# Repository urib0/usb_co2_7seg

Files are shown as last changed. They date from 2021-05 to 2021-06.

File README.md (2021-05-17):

# usb_co2_7seg

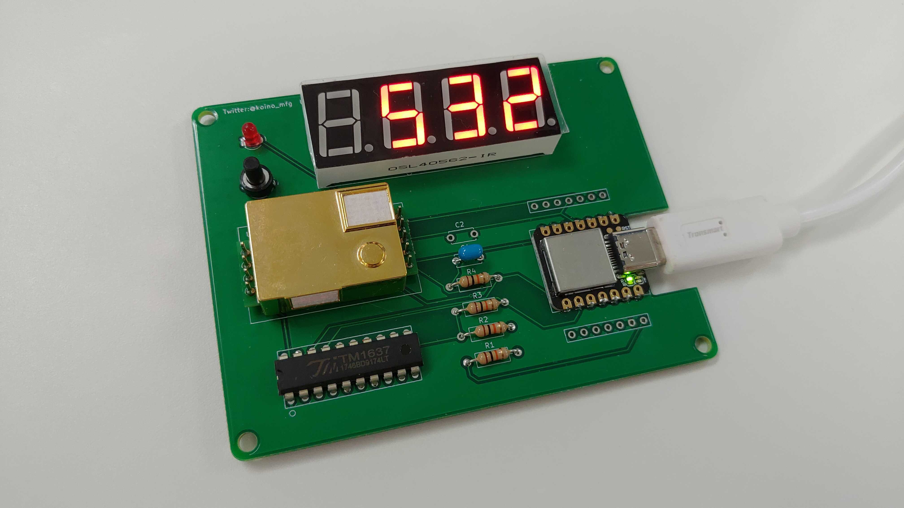
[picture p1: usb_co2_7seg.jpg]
usb_co2_7seg


Mac, Linux マシンに USB で接続できて追加ドライバ不要で値を読める CO2 と 7 セグ表示器

## 使い方(macOS)

まず、USB 機器をすべてコンピュータから取り外す。

次に、usb_co2_7seg を USB ポートに接続する。

次に、コンピュータに接続されているシリアルポートの一覧を表示する。

```
$ ls -1 /dev/cu.*
/dev/cu.Bluetooth-Incoming-Port
/dev/cu.iMiminashi5s-WirelessiAP
/dev/cu.usbmodem14101
```

上記の例の場合、`cu.usbmodem14101` というデバイスファイルが usb_co2_7seg を示す。

次に、`stty`コマンドを実行してシリアルポートの設定を行う。

```sh
stty -f /dev/cu.usbmodem14101 raw 9600
```

最後に、`cat`コマンドでデバイスファイルを読み込むと CO2 の値(ppm)が表示される。

```
$ cat /dev/cu.usbmodem14101
co2=399;status=0
co2=399;status=0
co2=399;status=0
co2=399;status=0
co2=399;status=0
co2=399;status=0
```

## 使い方(Linux)

まず、USB 機器をすべてコンピュータから取り外す。

次に、usb_co2_7seg を USB ポートに接続する。

次に、コンピュータに接続されているシリアルポートの一覧を表示する。

```
$ ls -1 /dev/tty*
/dev/tty
.
. (中略)
.
/dev/ttyACM0
/dev/ttyAMA0
/dev/ttyprintk
/dev/ttyUSB0
```

上記の例の場合、`/dev/ttyACM0` というデバイスファイルが usb_co2_7seg を示す。

次に、`stty`コマンドを実行してシリアルポートの設定を行う。

```sh
stty -F /dev/ttyACM0 raw 9600
```

最後に、`cat`コマンドでデバイスファイルを読み込むと CO2 の値(ppm)が表示される。

```
$ cat /dev/ttyACM0
co2=399;status=0
co2=399;status=0
co2=399;status=0
co2=399;status=0
co2=399;status=0
```

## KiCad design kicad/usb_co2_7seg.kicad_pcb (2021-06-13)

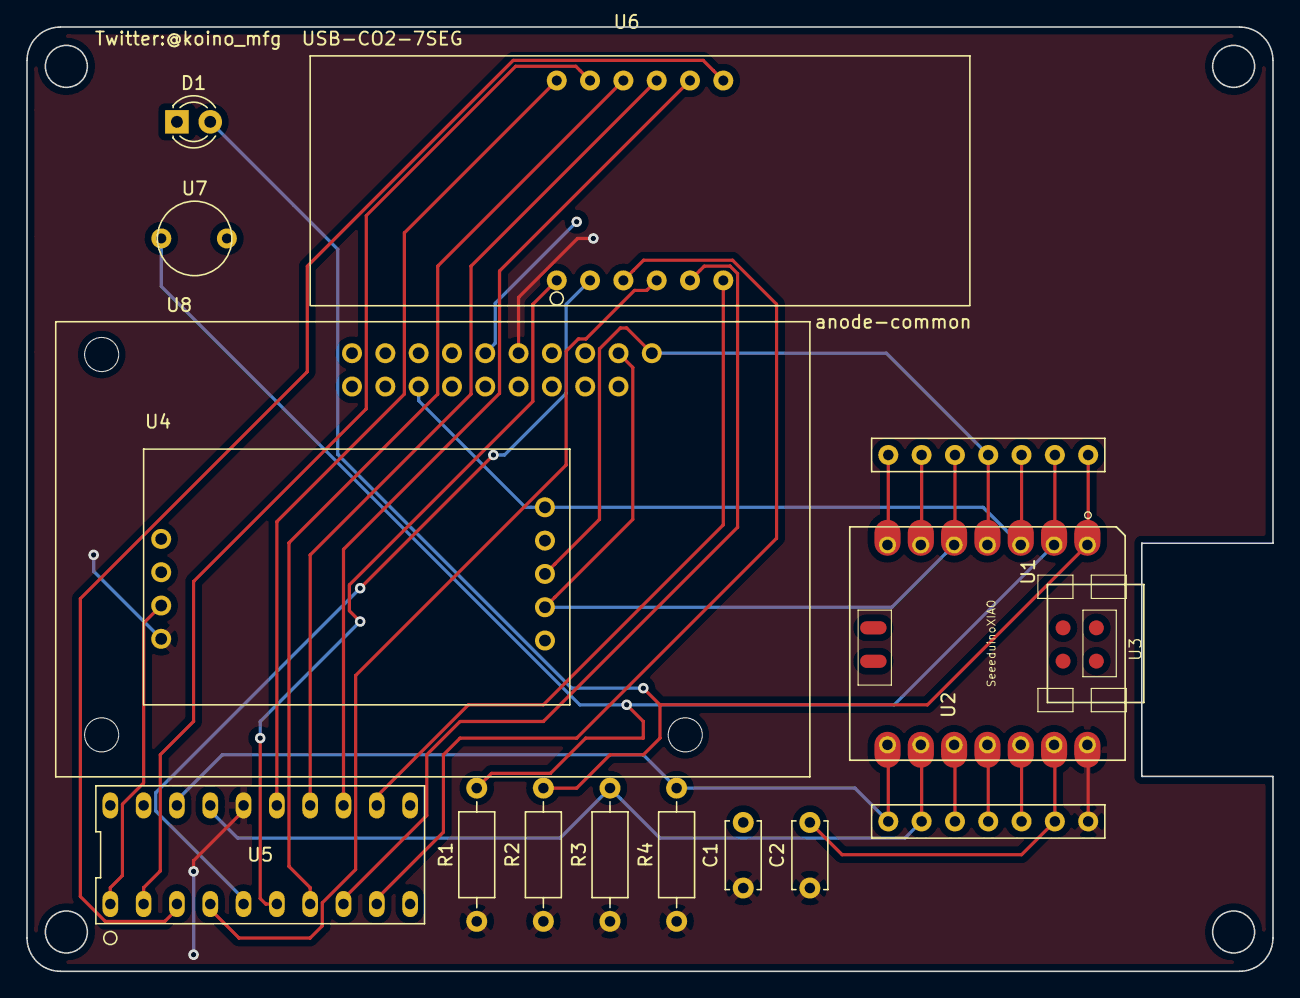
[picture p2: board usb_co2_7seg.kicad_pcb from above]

Board: 2 copper layers, 95.0 x 72.0 mm, 15 parts (0 on the bottom side), 26 nets.

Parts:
C1, C2: C; C_Disc_D5.0mm_W2.5mm_P5.00mm
D1: LED; LED_D3.0mm
R1, R2, R3, R4: R; R_Axial_DIN0207_L6.3mm_D2.5mm_P10.16mm_Horizontal
U1, U2: PinHeader_XIAO
U3: SeeeduinoXIAO; SeeedXIAO
U4: MH-Z19B
U5: TM1637; TM1630
U6: 7segment_led; 7segment_led_0.56
U7: SW_push_2pin; SW_PUSH_2pin
U8: MH-Z14A

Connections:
+5V: C1.1, C2.1, R1.1, R2.1, R3.1, R4.1, U2.7, U3.14, U4.9, U5.16, U8.1
GND: C1.2, C2.2, D1.1, U2.6, U3.13, U4.8, U5.1, U7.2, U8.3
unnamed: D1.2, R2.2, U1.1, U3.1
unnamed: R1.2, U1.2, U3.2, U7.1
unnamed: R3.2, U2.2, U3.9, U5.17
unnamed: R4.2, U2.1, U3.8, U5.18
unnamed: U1.3, U3.3, U4.1, U8.8
unnamed: U1.4, U3.4, U4.3, U8.19
unnamed: U1.5, U3.5, U4.4, U8.18
unnamed: U1.6, U3.6
unnamed: U1.7, U3.7
unnamed: U2.3, U3.10
unnamed: U2.4, U3.11
unnamed: U2.5, U3.12
unnamed: U5.2, U6.11
unnamed: U5.3, U6.7
unnamed: U5.4, U6.4
unnamed: U5.5, U6.2
unnamed: U5.6, U6.1
unnamed: U5.7, U6.10
unnamed: U5.8, U6.5
unnamed: U5.9, U6.3
unnamed: U5.12, U6.6
unnamed: U5.13, U6.8
unnamed: U5.14, U6.9
unnamed: U5.15, U6.12

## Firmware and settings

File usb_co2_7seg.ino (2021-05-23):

#include "TM1637.h"

#define LED_ON HIGH
#define LED_OFF LOW
#define SW_ON LOW
#define SW_OFF HIGH
#define PIN_LED 0
#define PIN_SW1 1
#define PIN_CLK 7
#define PIN_DIO 8
#define INTERVAL_UPDATE 1000
#define INTERVAL_LOOP 10
#define SW_LONG_PUSH_TIME 3
#define THRESHOLD 800
#define SERIAL_TX_MARGIN 13
#define STRING_MAX 4
#define RESULT_OK 0
#define RESULT_NG 1

typedef unsigned char uchar;
typedef unsigned int uint;

TM1637 tm = TM1637(PIN_CLK, PIN_DIO);

static char co2_strings[STRING_MAX + 1] = {0};

void setup()
{
    int co2_dummy = 0;

    digitalWrite(LED_BUILTIN, LED_OFF);
    digitalWrite(PIN_LED, LED_OFF);
    pinMode(LED_BUILTIN, OUTPUT);
    pinMode(PIN_LED, OUTPUT);
    pinMode(PIN_SW1, INPUT);

    Serial.begin(9600);
    /*
    while (!Serial)
    {
        ; // wait for serial port to connect
    }
    */
    tm.init();

    usb_mhz14a_init();
    usb_mhz14a_co2_request();
    delay(100);
    usb_mhz14a_get_co2(&co2_dummy);
    digitalWrite(LED_BUILTIN, LED_ON);
}

void loop()
{
    static int co2_value = 0;
    static int co2_status = 0;
    static int interval_cnt = INTERVAL_UPDATE;

    // ポーリング処理
    if (0 == usb_mhz14a_co2_is_ready())
    {
        co2_status = usb_mhz14a_get_co2(&co2_value);
        if (0 == co2_status)
        {
            writeIndicator(co2_value);
        }
    }

    // インターバル処理
    if (0 >= interval_cnt)
    {
        writeSerial(co2_value, co2_status);
        writeDisplay(co2_value);
        usb_mhz14a_co2_request();
        if (RESULT_OK == check_sw_long_push(PIN_SW1))
        {
            digitalWrite(PIN_LED, LED_ON);
        }
        else
        {
            digitalWrite(PIN_LED, LED_OFF);
        }
    }

    if (0 >= interval_cnt)
    {
        interval_cnt = INTERVAL_UPDATE - SERIAL_TX_MARGIN;
    }
    interval_cnt -= INTERVAL_LOOP;

    delay(INTERVAL_LOOP);
}

void writeIndicator(int co2_value)
{
    if (co2_value < THRESHOLD)
    {
        digitalWrite(PIN_LED, LED_OFF);
    }
    else
    {
        digitalWrite(PIN_LED, LED_ON);
    }
}

void writeSerial(int co2_val, int co2_status)
{
    Serial.print("co2=");
    Serial.print(co2_val, DEC);
    Serial.print(";status=");
    Serial.print(co2_status);
    Serial.print("\n");
}

void writeDisplay(int co2_val)
{
    uchar string_size = 0;

    int_to_char_arr(co2_val, co2_strings, &string_size);
    tm.clearDisplay();
    for (uchar uc_loop_cnt = 0; uc_loop_cnt < string_size; uc_loop_cnt++)
    {
        tm.setDigit(STRING_MAX - uc_loop_cnt - 1, co2_strings[uc_loop_cnt] - 0x30, false);
    }
    buff_clr(co2_strings, STRING_MAX + 1);
}

int check_sw_long_push(int pin)
{
    static int long_push_cnt = SW_LONG_PUSH_TIME;
    int ret = RESULT_NG;

    if (SW_ON == digitalRead(pin))
    {
        long_push_cnt--;
    }
    else
    {
        long_push_cnt = SW_LONG_PUSH_TIME;
    }

    if (0 >= long_push_cnt)
    {
        ret = RESULT_OK;
    }

    return ret;
}

void int_to_char_arr(int num, char *buff, uchar *size)
{
    if (num >= 1000)
    {
        buff[3] = (num / 1000) + 0x30;
        *size += 1;
    }
    if (num >= 100)
    {
        buff[2] = ((num / 100) % 10) + 0x30;
        *size += 1;
    }
    if (num >= 10)
    {
        buff[1] = ((num / 10) % 10) + 0x30;
        *size += 1;
    }
    if (num >= 0)
    {
        buff[0] = (num % 10) + 0x30;
        *size += 1;
    }
}

void buff_clr(char *buff, uchar cnt)
{
    for (uchar i = 0; i < cnt; i++)
    {
        buff[i] = 0;
    }
}

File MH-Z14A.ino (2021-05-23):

#include <SoftwareSerial.h>

#define CALIB_TIME 30 // per min
#define RESULT_OK 0
#define RESULT_NG 1

//SoftwareSerial mySerial(14, 15); // RX, TX for WNPink
//SoftwareSerial mySerial(16, 10); // RX, TX for ProMicro
SoftwareSerial mySerial(3, 4); // RX, TX for Seeduino XIAO

static byte command_get_co2[] = {
    0xFF, // Byte 0
    0x01, // Byte 1
    0x86, // Byte 2
    0x00, // Byte 4
    0x00, // Byte 5
    0x00, // Byte 6
    0x00, // Byte 7
    0x00, // Byte 8
    0x79  // Byte 9
};

static byte command_abc_off[] = {
    0xFF, // Byte 0
    0x01, // Byte 1
    0x79, // Byte 2
    0x00, // Byte 4
    0x00, // Byte 5
    0x00, // Byte 6
    0x00, // Byte 7
    0x00, // Byte 8
    0x86  // Byte 9
};

static byte command_abc_on[] = {
    0xFF, // Byte 0
    0x01, // Byte 1
    0x79, // Byte 2
    0xA0, // Byte 4
    0x00, // Byte 5
    0x00, // Byte 6
    0x00, // Byte 7
    0x00, // Byte 8
    0xE6  // Byte 9
};

static byte command_zero_calibration[] = {
    0xFF, // Byte 0
    0x01, // Byte 1
    0x87, // Byte 2
    0x00, // Byte 4
    0x00, // Byte 5
    0x00, // Byte 6
    0x00, // Byte 7
    0x00, // Byte 8
    0x78  // Byte 9
};

void usb_mhz14a_init()
{
  mySerial.begin(9600);
  delay(10);
  usb_mhz14a_abc_off();
  delay(10);
}

void usb_mhz14a_co2_request()
{
  mySerial.write(command_get_co2, sizeof(command_get_co2));
}

int usb_mhz14a_co2_is_ready()
{
  if (8 < mySerial.available())
  {
    return RESULT_OK;
  }

  return RESULT_NG;
}

int usb_mhz14a_get_co2(int *value)
{
  int c = 0;
  int message[9] = {0};
  int ret = 0;

  while (mySerial.available())
  {
    int b = mySerial.read();
    if ((c == 0 && b == 0xFF) || (c >= 1 && c <= 8))
    {
      message[c] = b;
      c++;
    }
  }

  int high_byte = message[2];
  int low_byte = message[3];
  *value = high_byte * 256 + low_byte;

  if (0 > *value)
  {
    return RESULT_NG;
  }

  return RESULT_OK;
}

void usb_mhz14a_abc_off()
{
  mySerial.write(command_abc_off, sizeof(command_abc_off));

  delay(10);
}

void usb_mhz14a_abc_on()
{
  mySerial.write(command_abc_on, sizeof(command_abc_on));

  delay(10);
}

void usb_mhz14a_zero_calibration()
{
  int cnt = 0;

  for (cnt = 0; cnt < (CALIB_TIME * 60); cnt++)
  {
    delay(1000);
  }

  mySerial.write(command_zero_calibration, sizeof(command_zero_calibration));

  delay(10);
}

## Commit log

2021-04-15 回路図をひいた
    [usb_soil_moisture.sch]
2021-05-04 ファイル名を修正
    [usb_co2_7seg.sch]
2021-05-04 配置だけした
    [usb_co2_7seg.kicad_pcb]
2021-05-04 配線済み DRC ok
    [usb_co2_7seg.kicad_pcb]
2021-05-04 プロットの設定を更新
    [usb_co2_7seg.kicad_pcb]
2021-05-16 usb_7segからコピー
2021-05-16 とりあえず動く
2021-05-16 しきい値を超えたら警告のLEDを点灯するようにした
2021-05-17 外観写真を追加
2021-05-17 READMEを追加
2021-05-17 スタンドアロンでも使えるようシリアルの接続待ちをやめた
2021-05-17 内容を移行した
2021-05-17 フォーマッタをかけた
2021-05-17 誤記を修正
2021-05-23 基板に存在しないSW2を消してSW1を定義し直した
2021-05-23 初期化時に自動校正をOFFにするようにした
2021-05-23 ファイル名を変更
2021-05-23 SWの長押しチェックを追加
2021-05-23 メインループの周期を1msから10msに変更した
2021-05-23 ポーリングと周期処理でブロックを分けた
2021-05-23 変数の命名規則を統一
2021-05-23 7セグLEDに表示する処理を別関数にした
2021-05-23 CO2濃度のシリアル出力を別関数にした
2021-05-23 CO2値のシリアル出力と7セグLEDへの表示を周期処理に移した
2021-05-23 基板上の警告LEDを点灯する処理を別関数にした
2021-05-23 制御対象を引数にして明確化した
2021-06-13 MH-Z14Aに対応 ERC OK
    [usb_co2_7seg.sch]
2021-06-13 部品の仮置き
    [usb_co2_7seg.kicad_pcb]
2021-06-13 MH-Z14Aの不要なピンを未接続にした
    [usb_co2_7seg.sch]
2021-06-13 配置配線完了 DRC OK
2021-06-13 ガーバー出力用の設定をした
    [usb_co2_7seg.kicad_pcb]
